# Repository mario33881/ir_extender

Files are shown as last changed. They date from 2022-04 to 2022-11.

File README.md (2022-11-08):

# IR EXTENDER



L'IR Extender e' composto da due dispositivi:
* un dispositivo e' collegato ad un ricevitore infrarossi e alla rete Wi-Fi
* un altro dispositivo e' collegato ad un trasmettitore infrarossi e alla rete Wi-Fi
    > Le due reti Wi-Fi possono essere due reti differenti o la stessa rete.
* i dispositivi comunicano attraverso una piattaforma cloud.

I dispositivi utilizzano il protocollo MQTT per comunicare.

Il sistema e' formato da 3 componenti principali:
* Publisher MQTT: e' il dispositivo che ha il ricevitore infrarossi. 

    Il suo compito e':
    1. Ricevere un segnale infrarossi da un telecomando
    2. Inviare l'informazione del segnale infrarossi, utilizzando la rete Wi-Fi, con il protocollo MQTT al Broker MQTT

* Broker MQTT: e' un servizio fornito in cloud.

    Come fornitore del servizio abbiamo scelto [HiveMQ](https://www.hivemq.com/): non richiede carta di credito per registrarsi e ha una versione di prova gratuita.

    Il suo compito e':
    1. Ricevere l'informazione proveniente dal Publisher MQTT
    2. Inviare l'informazione MQTT al Subscriber MQTT

    Utilizzando un servizio in cloud non dobbiamo preoccuparci di configurarlo.

* Subscriber MQTT: e' il dispositivo che ha il trasmettitore infrarossi.

    Il suo compito e':
    1. Ricevere l'informazione dal Broker MQTT
    2. Inviare un segnale infrarossi con l'informazione del Broker MQTT con il trasmettitore infrarossi

I dispositivi sono schede NodeMCU per permettere di sviluppare velocemente e comodamente gli sketch arduino.

---

## Requisiti progetto

* [X] Completare il codice del receiver: fatto
* [X] Completare il codice del transmitter: fatto
* [X] Utilizzare una piattaforma cloud ([HiveMQ](https://www.hivemq.com/)): fatto
* [X] Scrivere la documentazione in LaTeX: fatto
* [X] Creare schemi in fritzing per la documentazione: fatto

## Autori

- [Davide Pizzoli](https://github.com/pizidavi)
- [Stefano Zenaro](https://github.com/mario33881)

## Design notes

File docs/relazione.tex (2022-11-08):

\documentclass[a4paper,11pt]{article}

\usepackage[utf8]{inputenc}
\usepackage[italian]{babel}
\usepackage[sfdefault]{roboto}
\usepackage{layaureo} % reduce margins
\usepackage{url}
\usepackage{hyperref}
\usepackage{graphicx}
\usepackage{float}
\usepackage{alertmessage}

% Setup
\hypersetup{hidelinks}
\hyphenation{knolleary}
\hyphenation{crankyoldgit}

% Document
\begin{document}
\title{IR Extender}
\author{Davide Pizzoli \\ Stefano Zenaro}
\date{Aprile 2022}

\pagenumbering{gobble}

% Title
\begin{titlepage}
  \maketitle
  \thispagestyle{empty}
\end{titlepage}

% Table of contents
\tableofcontents
\addcontentsline{toc}{section}{Indice}
\clearpage

\pagenumbering{arabic}

% Contents
\section{Descrizione}

    L'IR Extender permette di controllare da remoto dispositivi infrarossi a lunga distanza attraverso Internet.

    \begin{figure}[H]
      \centering
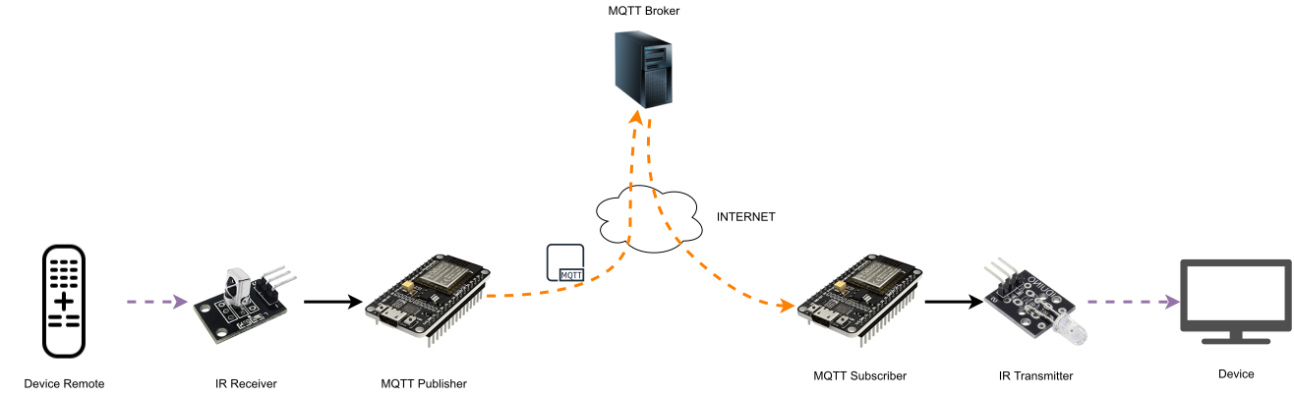
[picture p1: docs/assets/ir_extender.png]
      
      \caption{IR Extender}
    \end{figure}

    Il sistema è composto da 3 componenti:
    \begin{itemize}
      \item Ricevitore: riceve un segnale infrarossi e lo comunica al Broker MQTT attraverso un messaggio
      \item Broker MQTT: permette lo scambio di messaggi tra Ricevitore e Trasmettitore
      \item Trasmettitore: riceve il messaggio dal Broker MQTT e propaga il segnale infrarossi verso il dispositivo da controllare
    \end{itemize}

    \alertinfo{Ricevitore e trasmettitore possono essere collegati alla stessa rete \mbox{Wi-Fi} oppure a due reti \mbox{Wi-Fi} differenti.}

\section{Configurazione}

    \subsection{Prerequisiti}

    Componenti elettronici:
    \begin{itemize}
      \item IR Receiver
      \item IR Transmitter
      \item ESP32 * 2
      \item Jumpers * 6
    \end{itemize}

    \begin{samepage}
      \noindent
      Servizi cloud:
      \begin{itemize}
        \item Broker MQTT (es. \href{https://www.hivemq.com/}{HiveMQ})
      \end{itemize}
    \end{samepage}

    \begin{samepage}
      \noindent
      Librerie:
      \begin{itemize}
        \item Espressif 32: supporto alla board ESP32.
        \item PubSubClient (knolleary): libreria per la comunicazione attraverso il protocollo MQTT
        \item IRremoteESP8266 (crankyoldgit): libreria per inviare/ricevere segnali infrarossi
      \end{itemize}
    \end{samepage}

    \subsection{Broker MQTT (HiveMQ)}
    \label{subsec:Broker}

    Per permettere la comunicazione tra ricevitore e trasmettitore è prima necessario configurare il broker MQTT:

    \begin{enumerate}
      \item \href{https://console.hivemq.cloud/}{Registrarsi su HiveMQ}
      \item Creare un nuovo \emph{Cluster}
        \begin{figure}[H]
          \centering
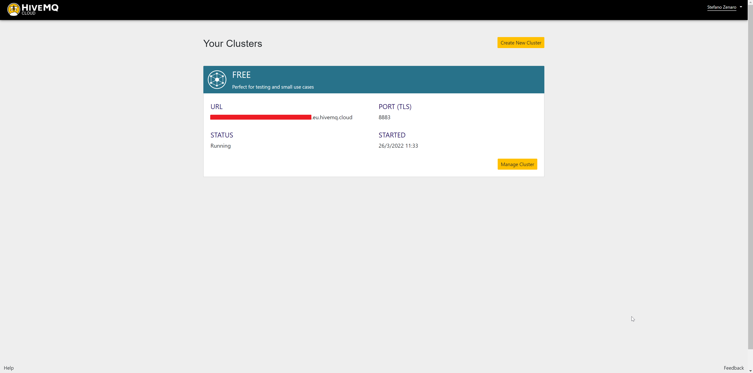
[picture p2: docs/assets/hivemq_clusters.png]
          
        \end{figure}

        Salvarsi l'\emph{URL} del Cluster, che sarà utilizzato per configurare il Ricevitore e il Trasmettitore.

      \item Cliccare su \emph{Manage cluster}
        \begin{figure}[H]
          \centering
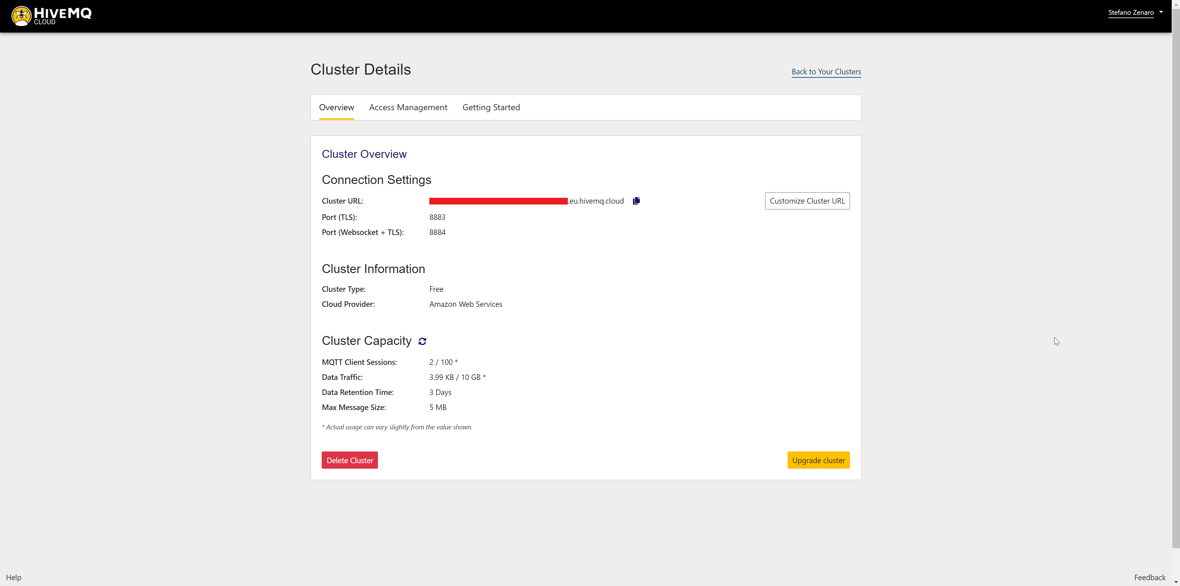
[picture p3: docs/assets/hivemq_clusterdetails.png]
          
        \end{figure}

      \item Nella sezione \emph{Access Management} aggiungere delle credenziali di accesso al \emph{Cluster}
        \begin{figure}[H]
          \centering
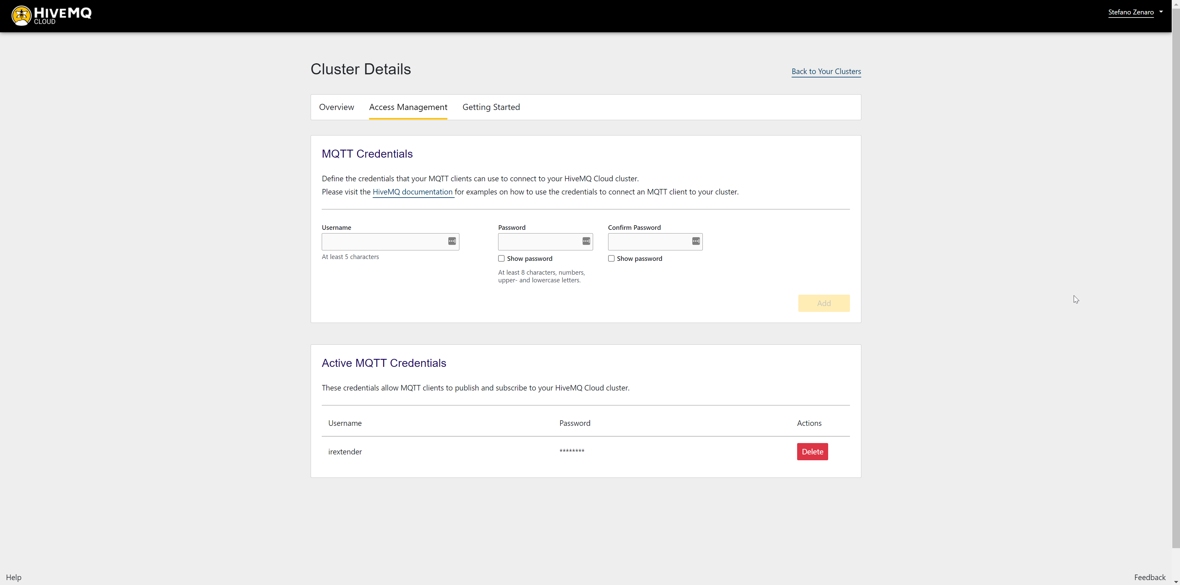
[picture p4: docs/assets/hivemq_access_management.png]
          
        \end{figure}

    \end{enumerate}

    \subsection{Ricevitore}
    \label{subsec:receiver}

    Il dispositivo ricevitore si occupa di:

    \begin{enumerate}
      \item Ricevere un segnale infrarossi da un telecomando
      \item Inviare l'informazione del segnale infrarossi, utilizzando la rete Wi-Fi, con il protocollo MQTT al Broker MQTT
    \end{enumerate}

    Per predisporre il ricevitore a ricevere segnali infrarossi e ad inoltrarli al broker MQTT occorre:

    \begin{itemize}
      \item Collegare il ricevitore infrarossi all'ESP32 (figura~\ref{fig:circuito_ricevitore}):
        \begin{itemize}
          \item Il ground del ricevitore al pin GND;
          \item VCC al pin 3V3;
          \item data/signal al pin G13/13;
        \end{itemize}

        \alertinfo{Assicurarsi di collegare correttamente l'alimentazione e il cavo dati verificando il pinout del ricevitore infrarossi e dell'ESP32. I pin potrebbero essere posizionati diversamente (da scheda a scheda, da sensore a sensore) rispetto allo schema nella figura~\ref{fig:circuito_ricevitore}.}

      \item Aprire la cartella \texttt{receiver/src}
      \item Rinominare il file \texttt{secrets.h.sample} in \texttt{secrets.h} e aprirlo
      \item Inserire i dati di accesso della rete WiFi e del \hyperref[subsec:Broker]{Broker MQTT}
      \item Caricare il programma sull'ESP32
    \end{itemize}

    \begin{figure}[H]
      \centering
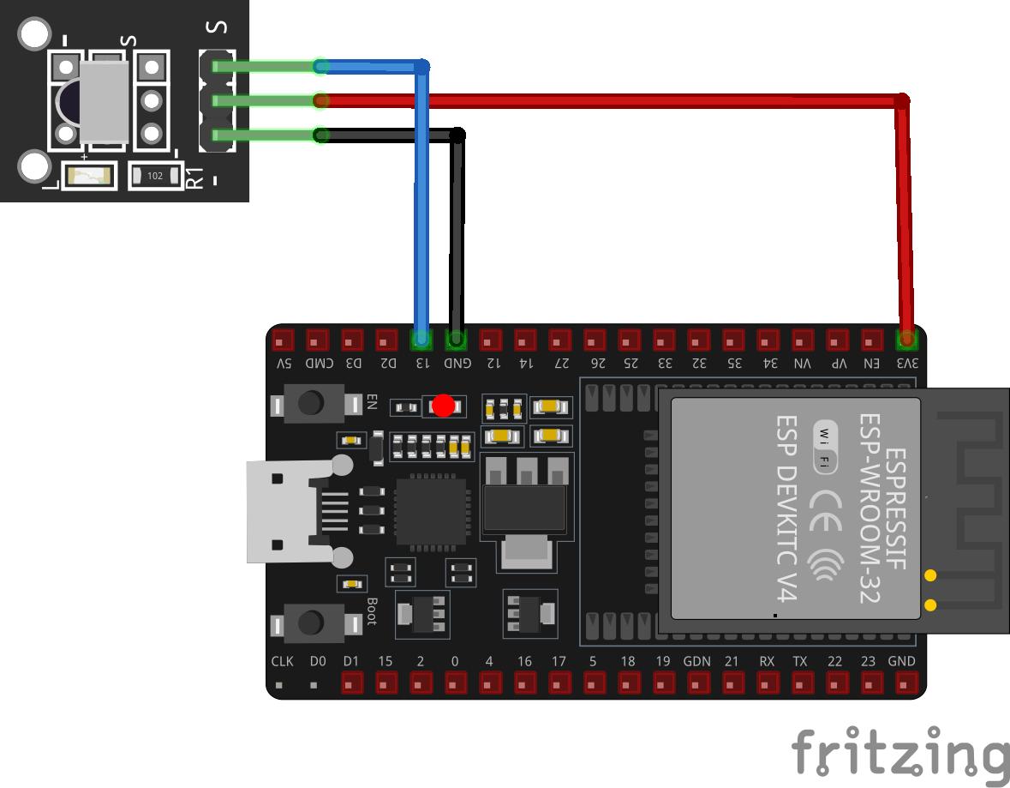
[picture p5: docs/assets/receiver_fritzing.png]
      
      \caption{Circuito Ricevitore}
      \label{fig:circuito_ricevitore}
    \end{figure}

    \subsection{Trasmettitore}
    \label{subsec:transmitter}

    Il dispositivo trasmettitore si occupa di:

    \begin{enumerate}
      \item Ricevere l'informazione dal Broker MQTT
      \item Inviare il segnale ricevuto tramite il trasmettitore infrarossi
    \end{enumerate}

    Per predisporre il trasmettitore a ricevere messaggi dal broker MQTT e di propagare segnali infrarossi occorre:

    \begin{itemize}
      \item Collegare il trasmettitore infrarossi all'ESP32 (figura~\ref{fig:circuito_trasmettitore}):
        \begin{itemize}
          \item Il ground del trasmettitore al pin GND;
          \item VCC al pin 3V3;
          \item data/signal al pin G12/12;
        \end{itemize}

        \alertinfo{Assicurarsi di collegare correttamente l'alimentazione e il cavo dati verificando il pinout del trasmettitore infrarossi e dell'ESP32. I pin potrebbero essere posizionati diversamente (da scheda a scheda, da sensore a sensore) rispetto allo schema nella figura~\ref{fig:circuito_trasmettitore}.}

      \item Aprire la cartella \texttt{transmitter/src}
      \item Rinominare il file \texttt{secrets.h.sample} in \texttt{secrets.h} e aprirlo
      \item Inserire i dati di accesso della rete WiFi e del \hyperref[subsec:Broker]{Broker MQTT}
      \item Caricare il programma sull'ESP32
    \end{itemize}

    \begin{figure}[H]
      \centering
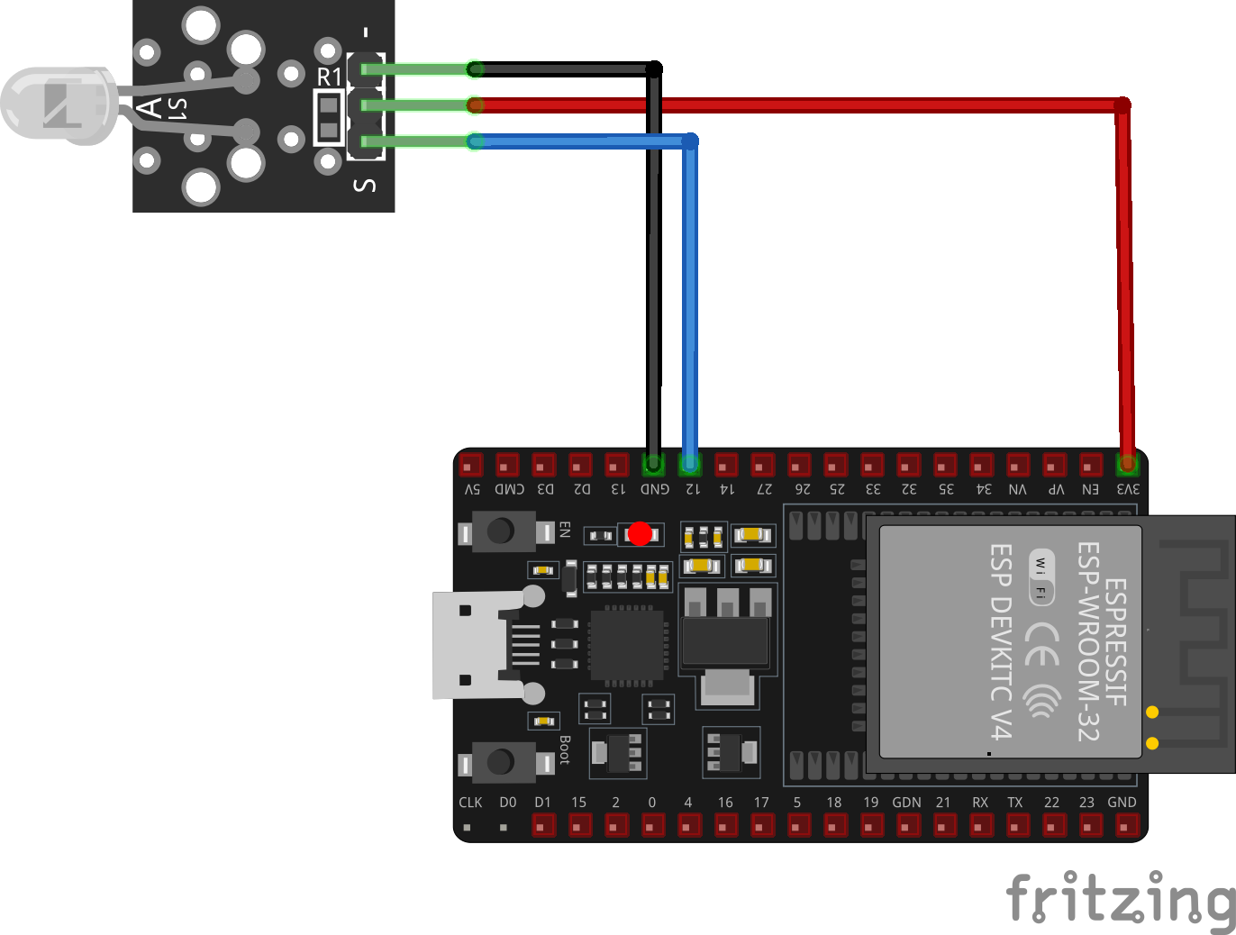
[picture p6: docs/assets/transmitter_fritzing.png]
      
      \caption{Circuito Trasmettitore}
      \label{fig:circuito_trasmettitore}
    \end{figure}

\section{Scelte progettuali}

    \subsection{Protocollo messaggio MQTT}

    La libreria che interpreta i dati rilevati dal sensore infrarossi può rilevare 3 tipi di protocolli:
    \begin{itemize}
      \item Protocollo a stati: composto da più di un valore. Usato, ad esempio, per i condizionatori.
      \item Protocollo semplice: formato da un singolo valore.
      \item Protocollo sconosciuto: non è stato possibile rilevare il protocollo. Verranno inviati tutti i valori rilevati durante la lettura.
    \end{itemize}

    \noindent
    Per gestire le 3 casistiche si è realizzato un protocollo per il messaggio MQTT:
    \smallskip

    Per i protocolli a stati verrà inviata una stringa con il formato:

    \begin{verbatim}
      <protocol>|<length>|<value1>,<value2>,...|<size>
    \end{verbatim}

    Dove:
    \begin{itemize}
      \item "protocol" è un identificativo del protocollo rilevato dal sensore IR
      \item "length" è il numero di valori "valueX"
      \item "valueX" sono valori \emph{raw} letti dal sensore IR
      \item "size" (in bit) verrà usato dal metodo send() con il trasmettitore IR
    \end{itemize}

    \bigskip

    \begin{samepage}
      Per i protocolli semplici verrà inviata una stringa con il formato:

      \begin{verbatim}
        <protocol>|1|<value>|<size>
      \end{verbatim}

      Dove:
      \begin{itemize}
        \item "protocol" è un identificativo del protocollo rilevato dal sensore IR
        \item "1" indica che c'è un solo valore letto
        \item "value" è il valore letto. Verrà usato dal metodo send() con il trasmettitore IR
        \item "size" (in bit) verrà usato dal metodo send() con il trasmettitore IR
      \end{itemize}
    \end{samepage}

    \bigskip

    \begin{samepage}
      Per i protocolli non riconosciuti verrà inviata una stringa con il formato:

      \begin{verbatim}
        -1|<length>|<value1>,<value2>,...|-1
      \end{verbatim}

      Dove:
      \begin{itemize}
        \item "-1" indica che il protocollo non è stato riconosciuto
        \item "length" è il numero di valori "valueX"
        \item "valueX" sono valori raw letti dal sensore IR. Questi valori verranno trasmessi dal metodo sendRaw() con il trasmettitore IR
        \item "-1" (size) indica "non applicabile" poichè il protocollo non richiede state[]
      \end{itemize}
    \end{samepage}

\section{Limitazioni trovate nello svolgimento del progetto}

    \subsection{Differenze nei segnali infrarossi per ogni produttore}

    Ogni produttore di dispositivi che utilizzano segnali ad infrarossi, crea un proprio protocollo per la decodifica dei segnali.
    Le differenze possono essere termini di pause tra un dato e l'altro, intensità e frequenze.

    Nel caso di un protocollo non riconosciuto il segnale verrà comunque letto come segnale grezzo e inviato, ma non è garantito il corretto funzionamento.

    \bigskip
    \noindent
    Una lista dei protocolli supportati è disponibile sulla \href{https://github.com/crankyoldgit/IRremoteESP8266/blob/master/SupportedProtocols.md}{pagina ufficiale della libreria IRremoteESP8266}

\section{Troubleshooting}

    \subsection{Segnale infrarossi non rilevato}

    Per non rilevare troppo rumore è stata modificata la dimensione del buffer di memoria usato per memorizzare i dati letti dal sensore infrarossi.

    È possibile cambiare la dimensione del buffer dal file \texttt{receiver/src/main.hpp} modificando la variabile "BUFFER\_SIZE": riducendo il valore aumenterà la velocità di lettura 
    del sensore infrarossi permettendo di leggere (dal sensore) e trasmettere (al broker MQTT) più valori ma aumentando la probabilità di rilevare rumore e quindi di ottenere dati inutilizzabili dal trasmettitore.
    Aumentando la dimensione del buffer rallenterà sensibilmente la velocità del sistema con il rischio che il sensore infrarossi non riuscirà a rilevare dati sufficienti per poterli spedire al broker MQTT.

\clearpage

% List of figures
\listoffigures
\addcontentsline{toc}{section}{\listfigurename}

\end{document}

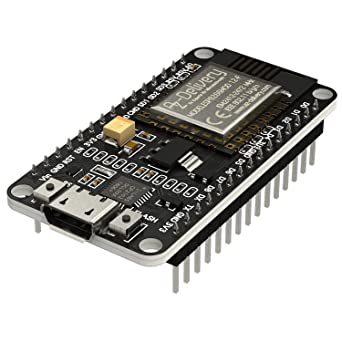
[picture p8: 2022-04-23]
docs/assets/nodemcu.jpg

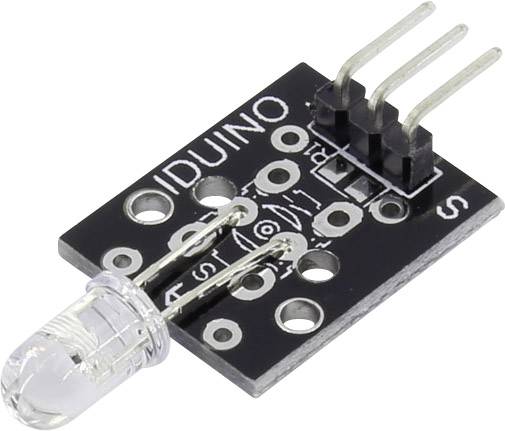
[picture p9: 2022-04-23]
docs/assets/ir_transmitter.jpg

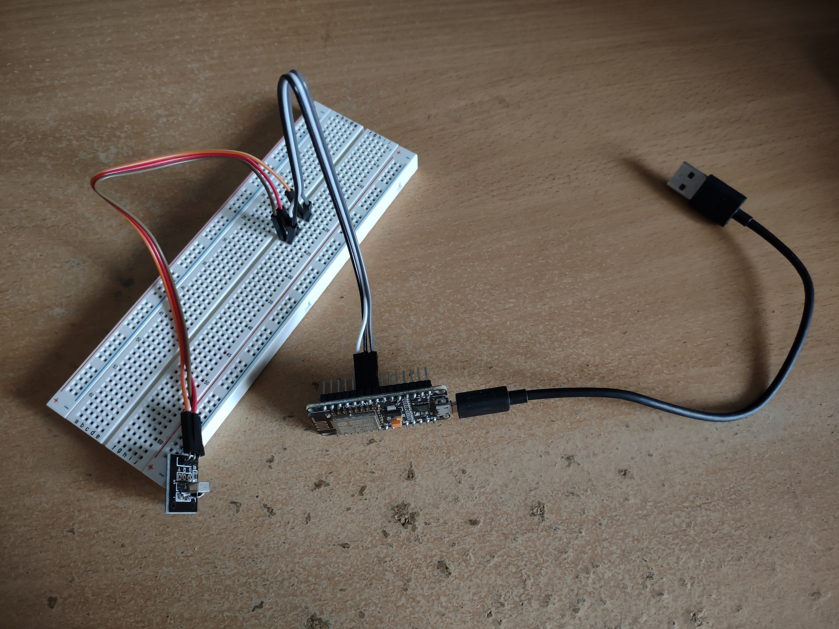
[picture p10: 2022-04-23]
docs/assets/receiver1.jpg

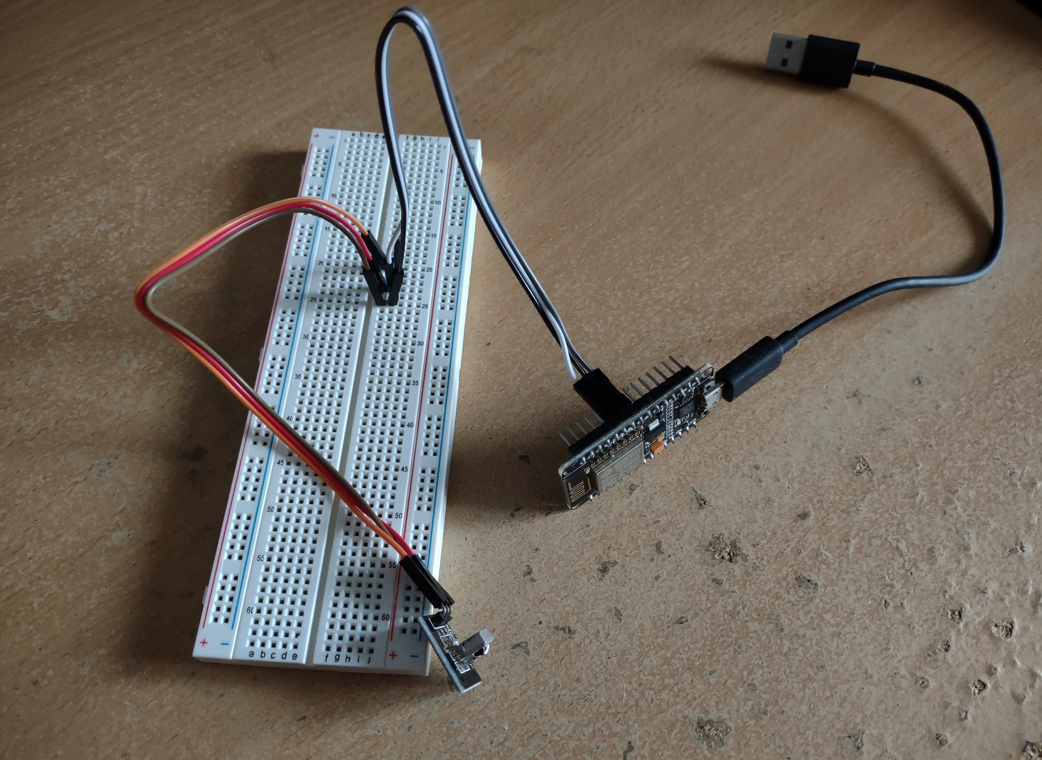
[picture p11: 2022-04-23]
docs/assets/receiver2.jpg

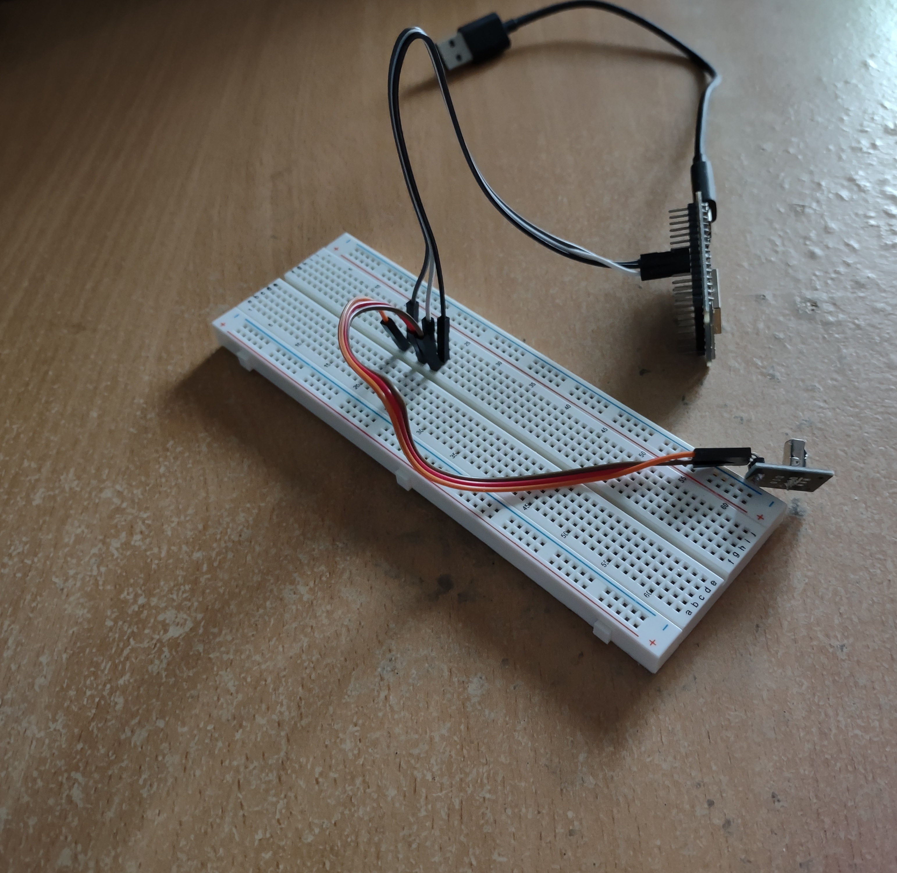
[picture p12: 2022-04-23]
docs/assets/receiver3.jpg

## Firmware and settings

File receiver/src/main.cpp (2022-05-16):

#include <Arduino.h>

#include <PubSubClient.h>

#ifdef NODEMCU_ESP8266
    #include <ESP8266WiFi.h>
    #include <time.h>
    #include <TZ.h>
    #include <FS.h>
    #include <LittleFS.h>
    #include <CertStoreBearSSL.h>
#else 
    #ifdef NODEMCU_ESP32
        #include <WiFi.h>
        #include <WiFiClientSecure.h>
    #else
        #error Board not supported
    #endif
#endif

#include <IRremoteESP8266.h>
#include <IRrecv.h>
#include <IRutils.h>

#include <Utils.hpp>

#include "main.hpp"
#include "secrets.h"

// Debug
const bool virtualIRrecv = false;

#ifdef NODEMCU_ESP8266
// A single, global CertStore which can be used by all connections.
// Needs to stay live the entire time any of the WiFiClientBearSSLs
// are present.
BearSSL::CertStore certStore;
#endif

WiFiClientSecure espClient;
PubSubClient * mqttClient;

IRrecv irrecv(RECV_PIN, BUFFER_SIZE, TIMEOUT, false);
decode_results ir_data;


/**
 * Si connette alla rete Wi-Fi.
 *
 * Macro:
 * - WIFI_SSID: SSID della rete Wi-Fi a cui connettersi
 * - WIFI_PASS: password della rete Wi-Fi
*/
void connect_wifi() {
    delay(10);
    Serial.println();
    Serial.print("Connecting to ");
    Serial.println(WIFI_SSID);

    WiFi.mode(WIFI_STA);  // modalita' stazione: connettiti ad una rete wireless esistente
    WiFi.begin(WIFI_SSID, WIFI_PASS);

    while (WiFi.status() != WL_CONNECTED) {
        delay(500);
        Serial.print(".");
    }

    randomSeed(micros());

    Serial.println("");
    Serial.println("WiFi connected");
    Serial.print("IP address: ");
    Serial.println(WiFi.localIP());
}


#ifdef NODEMCU_ESP8266
/**
 * Imposta la data corretta connettendosi ad un server NTP.
 *
 * Necessario per validare i certificati SSL.
*/
void setDateTime() {
    configTime(TZ_Europe_Rome, "pool.ntp.org", "time.nist.gov");

    Serial.print("Waiting for NTP time sync: ");
    time_t now = time(nullptr);
    while (now < 8 * 3600 * 2) {
        delay(100);
        Serial.print(".");
        now = time(nullptr);
    }
    Serial.println();

    struct tm timeinfo;
    gmtime_r(&now, &timeinfo);
    Serial.printf("%s %s", tzname[0], asctime(&timeinfo));
}
#endif


/**
 * Si connette al server MQTT.
 *
 * Se ci riesce manda un messaggio al topic "connected" indicando che il dispositivo si e' connesso correttamente
 *
 * Macro:
 * - MQTT_CLIENT_ID: identificativo del client MQTT
 * - MQTT_USER: username MQTT
 * - MQTT_PASS: password MQTT
*/
void connect_mqtt() {

    while (!mqttClient->connected()) {
        Serial.print("Attempting MQTT connection...");

        // Attempt to connect
        if (mqttClient->connect(MQTT_CLIENT_ID, MQTT_USER, MQTT_PASS)) {
            Serial.println(" connected");
            mqttClient->publish("connected", "Receiver connected successfully");
        }
        else {
            Serial.print(" failed, rc = ");
            Serial.print(mqttClient->state());
            Serial.println(" try again in 5 seconds");
            delay(5000);
        }
    }
}


/**
 * Invia il valore letto dal sensore IR tramite MQTT.
*/
void send_ir_msg(String value){
    Serial.print("Published message: ");
    Serial.println(value);
    mqttClient->publish("signal", value.c_str());
}


/**
 * Configurazione iniziale:
 * - Per debugging apre il monitor seriale e imposta come output il pin del LED sulla scheda.
 * - Abilita il ricevitore di segnali infrarossi e imposta un threshold per ridurre rumore rilevabile dal sensore IR
 * - Si connettite al Wi-Fi
 * - Imposta la data, necessaria per validare i Certificati SSL
 *   > solo su ESP8266
 * - Inizializza il file system per poter configurare il client MQTT per fargli usare i certificati SSL
 *   > solo su ESP8266
 * - Configura il client MQTT (URL e porta server, dimensione buffer messaggi) e lo usa per connettersi al broker MQTT
 *
 * Macro:
 * - BUFFER_SIZE: dimensione buffer letti dal sensore IR
 * - MQTT_SERVER: url del server MQTT
*/
void setup() {

    Serial.begin(115200);
    pinMode(LED_BUILTIN, OUTPUT);

    irrecv.setUnknownThreshold(BUFFER_SIZE+1);  // riduce probabilita' di leggere rumore
    irrecv.enableIRIn();

    connect_wifi();

    #ifdef NODEMCU_ESP8266

    setDateTime();

    // -- Certificati SSL
    // inizializza il file system
    LittleFS.begin();

    // cerca i certificati nel file system
    int numCerts = certStore.initCertStore(LittleFS, PSTR("/certs.idx"), PSTR("/certs.ar"));
    Serial.printf("Number of CA certs read: %d\n", numCerts);
    if (numCerts == 0) {
        Serial.printf("No certs found. Did you run certs-from-mozilla.py and upload the LittleFS directory before running?\n");
        return;
    }

    // configura il client per usare i certificati
    BearSSL::WiFiClientSecure *bear = new BearSSL::WiFiClientSecure();
    bear->setCertStore(&certStore);
    mqttClient = new PubSubClient(*bear);
    #else
    espClient.setInsecure();
    mqttClient = new PubSubClient(espClient);
    #endif

    // imposta il server MQTT
    mqttClient->setServer(MQTT_SERVER, 8883);

    // imposta dimensione buffer dei messaggi
    mqttClient->setBufferSize(1024);

    // connettiti al broker MQTT
    connect_mqtt();

    // segnala fine del setup
    for (int i = 0; i < 3; i++) {
        successBlink();
        delay(500);
    }
}


/**
 * Esegui un blink per indicare "operazione eseguita con successo".
*/
void successBlink(){
    #if DEFAULT_LED_ACTIVE_LOW == true
    digitalWrite(LED_BUILTIN, HIGH);
    delay(500);
    digitalWrite(LED_BUILTIN, LOW);
    #else
    digitalWrite(LED_BUILTIN, LOW);
    delay(500);
    digitalWrite(LED_BUILTIN, HIGH);
    #endif
}

/**
 * Ripeti all'infinito:
 * - se non si e' connessi al Wi-Fi, connettiti.
 * - se non si e' connessi al Broker MQTT, connettiti.
 * - quando viene letto un valore del sensore IR, invialo tramite MQTT
 *   > Esegui il blink del LED della scheda per indicare che un nuovo valore e' stato letto dal sensore IR e trasmesso al broker MQTT
 *
 * I dati letti possono avere protocolli diversi:
 * - protocollo sconosciuto: non e' stato possibile riconoscere il protocollo. Verra' inviato un messaggio generico
 *
 *   Formato messaggio: "-1|<length>|<value1>,<value2>,...|-1"
 *   Dove:
 *   + "-1" indica che il protocollo non e' stato riconosciuto
 *   + "<length>" e' il numero di valori "<valueX>"
 *   + "<valueX>" sono valori raw letti dal sensore IR. Questi valori verranno trasmessi dal metodo sendRaw() con il trasmettitore IR
 *   + "-1" (size) indica "non applicabile" poiche' il protocollo non richiede state[]
 *
 * - protocollo con state: sono protocolli piu' complessi (ad esempio per i condizionatori)
 *
 *   Formato messaggio: "<protocol>|<length>|<value1>,<value2>,...|<size>"
 *   Dove:
 *   + "<protocol>" e' un identificativo del protocollo rilevato dal sensore IR
 *   + "<length>" e' il numero di valori "<valueX>"
 *   + "<valueX>" sono valori raw letti dal sensore IR
 *   + "<size>" (in bit) verra' usato dal metodo send() con il trasmettitore IR
 *
 * - protocollo semplice: il protocollo e' composto da un singolo valore
 *
 *   Formato messaggio: "<protocol>|1|<value>|<size>"
 *   Dove:
 *   + "<protocol>" e' un identificativo del protocollo rilevato dal sensore IR
 *   + "1" indica che c'e' un solo valore letto
 *   + "<value>" e' il valore letto. Verra' usato dal metodo send() con il trasmettitore IR
 *   + "<size>" (in bit) verra' usato dal metodo send() con il trasmettitore IR
*/
void loop() {

    if (WiFi.status() != WL_CONNECTED) {
        connect_wifi();
    }

    if (!mqttClient->connected()) {
        connect_mqtt();
    }
    mqttClient->loop();

    if (irrecv.decode(&ir_data)) {
        // visualizza informazioni utili sui dati letti
        Serial.print(resultToHumanReadableBasic(&ir_data));
        Serial.print("Overflow? ");
        Serial.println(ir_data.overflow);
        decode_type_t protocol = ir_data.decode_type;

        if (protocol == decode_type_t::UNKNOWN && ir_data.overflow == 0) {
            Serial.println("Protocollo sconosciuto");

            // Ottieni array valori letti in un formato comodo per la funzione sendRaw().
            uint16_t *raw_array = resultToRawArray(&ir_data);
            // Conta il numero di elementi dell'array
            uint16_t length = getCorrectedRawLength(&ir_data);

            // converti l'array in una stringa con formato "<length>|<val1>, <val2>,..." e invia al broker MQTT specificando che il protocollo e' sconosciuto
            String data_msg = uint16ArrayToString(raw_array, length);
            send_ir_msg(String(protocol) + "|" + data_msg + "|-1");

            // Dealloca memoria allocata da resultToRawArray().
            delete [] raw_array;

            successBlink();
        }
        else if (hasACState(protocol) && ir_data.overflow == 0) {
            // Il messaggio necessita dell'utilizzo di state[]
            Serial.print("Protocollo state: protocol = ");
            Serial.print(protocol);
            Serial.print(" | size = ");
            Serial.println(ir_data.bits);

            String data_msg = uint8ArrayToString(ir_data.state, sizeof(ir_data.state));
            send_ir_msg(String(protocol) + "|" + data_msg + "|" + String(ir_data.bits));
            successBlink();
        }
        else if (ir_data.overflow == 0) {
            // procollo semplice (esempio <= 64 bit)
            Serial.print("Protocollo semplice: Protocol = ");
            Serial.println(protocol);
            String value = uint64ToString(ir_data.value);
            send_ir_msg(String(protocol) + "|1|" + value + "|" + String(ir_data.bits));
            successBlink();
        }

        Serial.println("------------------------------------------------");
        irrecv.resume(); // Receive the next value
    }
    else if (virtualIRrecv){
        // debug
        send_ir_msg(String(random(0, 1000)));
        delay(2000);
        successBlink();
        Serial.println("------------------------------------------------");
    }
}

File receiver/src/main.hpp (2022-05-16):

#ifndef Main_h
#define Main_h

#include <WString.h>

#ifdef NODEMCU_ESP8266
    #define RECV_PIN 14  // Pin D5
#else
    #define RECV_PIN 13  // Pin G13
    #ifndef LED_BUILTIN
        #define LED_BUILTIN 2
    #endif
#endif

#define BUFFER_SIZE 1024      // dimensione buffer lettura dati dal sensore IR
#define TIMEOUT 50            // timeout del sensore IR

#define DEFAULT_LED_ACTIVE_LOW true  // vero = led attivo alto, falso = led attivo basso

void connect_wifi();
void connect_mqtt();
void send_ir_msg(String value);
void successBlink();
void setup();
void loop();

#ifdef NODEMCU_ESP8266
void setDateTime();
#endif

#endif // Main_h

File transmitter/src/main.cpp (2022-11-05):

#include <WiFi.h>
#include <WiFiClientSecure.h>
#include <PubSubClient.h>
#include <IRsend.h>
#include <IRrecv.h>
#include <IRremoteESP8266.h>
#include <IRutils.h>

#include <Utils.hpp>

#include "secrets.h"

#define IR_SEND_PIN 12
#define IR_FREQUENCY 38000


WiFiClientSecure espClient;
PubSubClient client(espClient);
IRsend IrSender(IR_SEND_PIN);


void callback(char* topic, byte* payload, unsigned int payload_length);
void connect_wifi();
void connect_mqtt();

void setup() {
  Serial.begin(9600);
  IrSender.begin();

  connect_wifi();

  espClient.setInsecure();
  // espClient.setCACert(root_ca); // Use certificate for server verification

  client.setServer(MQTT_SERVER, 8883);
  client.setBufferSize(1024);
  client.setCallback(callback);
}

void loop() {
  if (!client.connected())
    connect_mqtt();

  client.loop();
}

void callback(char* topic, byte* payload, unsigned int payload_length) {
  Serial.print("Message arrived in [");
  Serial.print(topic);
  Serial.println("] ");

  String message = "";
  for (int i = 0; i < payload_length; i++) {
    message += (char)payload[i];
  }

  String message_parts[4];
  split(message, '|', message_parts, 4);

  decode_type_t protocol = (decode_type_t)message_parts[0].toInt();
  int length = message_parts[1].toInt();
  String values(message_parts[2]);
  int size = message_parts[3].toInt();

  Serial.print("protocol = ");
  Serial.print(protocol);
  Serial.print("; values[");
  Serial.print(length);
  Serial.print("] = {");
  Serial.print(values);
  Serial.print("}");
  Serial.print("; size = ");
  Serial.print(size);
  Serial.println("");

  // Send IR signal
  if (protocol == decode_type_t::UNKNOWN) {
    String* values_array{ new String[length]{} };
    split(values, ',', values_array, length);

    uint16_t* rawData{ new uint16_t[length]{} };
    for (int i = 0; i < length; i++) {
      rawData[i] = (uint64_t)(values_array[i].toDouble());
    }

    IrSender.sendRaw(rawData, length, IR_FREQUENCY);
    Serial.println("IR sent via rawData");

    delete[] values_array;
    delete[] rawData;
  }
  else if (hasACState(protocol)) {
    uint64_t data = (uint64_t)(values.toDouble());
    IrSender.send(protocol, data, size / 8);
    Serial.println("IR sent with ACState");
  }
  else {
    uint64_t data = (uint64_t)(values.toDouble());
    IrSender.send(protocol, data, size);
    Serial.println("IR sent");
  }
}

void connect_wifi() {
  Serial.println();
  Serial.print("Connecting to WiFI");

  WiFi.mode(WIFI_STA);
  WiFi.begin(WIFI_SSID, WIFI_PASS);

  while (WiFi.status() != WL_CONNECTED) {
    delay(1000);
    Serial.print(".");
  }
  Serial.println(" connected");
  // Serial.print("IP address: ");
  // Serial.println(WiFi.localIP());
}

void connect_mqtt() {
  while (!client.connected()) {
    Serial.print("Connecting to MQTT... ");

    if (client.connect(MQTT_CLIENT_ID, MQTT_USER, MQTT_PASS)) {
      Serial.println("connected");
      client.publish("connected", "Transmitter connected");

      client.subscribe("signal");
    } else {
      Serial.print(" failed, rc = ");
      Serial.print(client.state());
      Serial.println(" try again in 5 seconds");
      delay(5000);
    }
  }
}

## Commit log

2022-04-23 + documentazione, codice receiver
    [receiver.fzz, transmitter.fzz]
2022-05-16 + esp32 support
2022-07-31 Transmitter: New message protocol (#4)
    * Changed device name
    * New protocol
    Changed IR library
    * Fix
    * IRremoteESP8266 library expects frequency in Hz
    [main.cpp]
2022-11-05 Replace vla (#5)
    * rimpiazzati VLA con allocazione dinamica
    * + warning a compilazione
    [main.cpp]
2022-11-08 Updated docs (#3)
    * Updated docs
    * fix grammar
    * modified documentation structure
    * Fixes & Improvements
    * fix typo
    * sostituiti schemi fritzing nodemcu con esp32
    * Fixed spaces
    * Fixed page style
    * Improvements
    * Added Limitations' section
    * fix grammar
    * replaced old documentation build
    [receiver.fzz, transmitter.fzz]
